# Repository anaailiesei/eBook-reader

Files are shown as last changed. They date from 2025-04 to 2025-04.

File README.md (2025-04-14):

# OpenBook

## 1. Diagrama Bloc
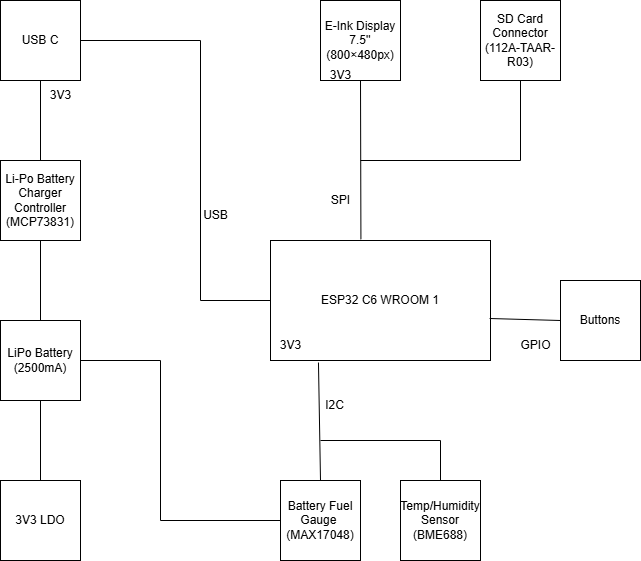
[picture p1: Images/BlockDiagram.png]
diagrama


## 2. BOM
|DEVICE |PARTS |PURCHASE URL |DATASHEET URL |
|---|---|---|---|
|ADAFRUIT_LEDCHIP-LED0603 |CHG_LED |https://www.tme.eu/en/details/kp-1608surck/smd-colour-leds/kingbright-electronic/ |https://www.alldatasheet.com/datasheet-pdf/pdf/1153370/TO-GRACE/KP-1608SURCK.html |
|EAGLE-LTSPICE_C |EPD_C5 |https://www.digikey.com/en/products/detail/samsung-electro-mechanics/CL05B104KB5NNNC/11696318 |https://www.digikey.com/en/products/detail/samsung-electro-mechanics/CL05B104KB5NNNC/11696318 |
|ESP32_WROVER_EAGLE-LTSPICE_R |R3 |https://www.digikey.com/en/products/detail/cts-resistor-products/73L1R47J/1543472 |https://www.digikey.com/en/products/detail/cts-resistor-products/73L1R47J/1543472 |
|ESP32_WROVER_EAGLE-LTSPICE_R |R1_PWRUSB |https://www.digikey.com/en/products/detail/yageo/RC0402JR-07100KL/726416 |https://www.digikey.com/en/products/detail/yageo/RC0402JR-07100KL/726416 |
|EAGLE-LTSPICE_C |C1, C2, C4_USB, C6, C8, C9, C10, C_DELAY |https://www.digikey.com/en/products/detail/samsung-electro-mechanics/CL05B104KP5NNNC/3886660 |https://www.digikey.com/en/products/detail/samsung-electro-mechanics/CL05B104KP5NNNC/3886660 |
|RCL_CPOL-EUCT3528 |C3 |https://ro.mouser.com/ProductDetail/KEMET/T491B107K006AT?qs=0CYHZL%252BGkuR7Fv7IsnkA2g%3D%3D |https://ro.mouser.com/ProductDetail/KEMET/T491B107K006AT?qs=0CYHZL%252BGkuR7Fv7IsnkA2g%3D%3D |
|ESP32_WROVER_EAGLE-LTSPICE_R |R1, R1_PINH, R1_PINH1, R2_PINH, R2_PINH1, R4, R5, R6, R7, R8, R9, R10, R_BOOT, R_CHANGE, R_CL1, R_RESET|https://www.digikey.com/en/products/detail/yageo/RC0402JR-0710KL/726418 |https://www.digikey.com/en/products/detail/yageo/RC0402JR-0710KL/726418 |
|EAGLE-LTSPICE_C |C7 |https://www.digikey.com/en/products/detail/samsung-electro-mechanics/CL05A106MP5NUNC/3887108 |https://www.digikey.com/en/products/detail/samsung-electro-mechanics/CL05A106MP5NUNC/3887108 |
|112A-TAAR-R03_ATTEND |J4 |https://www.digikey.com/en/products/detail/attend-technology/112A-TAAR-R03/17633923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 |https://www.digikey.com/en/products/detail/attend-technology/112A-TAAR-R03/17633923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 |
|ESP32_WROVER_EAGLE-LTSPICE_R |R_CAPACITOR |https://www.digikey.com/en/products/detail/te-connectivity-passive-product/CRGCQ0402F15R/8576207 |https://www.digikey.com/en/products/detail/te-connectivity-passive-product/CRGCQ0402F15R/8576207 |
|EAGLE-LTSPICE_C |C5 |https://www.digikey.com/en/products/detail/taiyo-yuden/JMK105BJ105KV-F/930583 |https://www.digikey.com/en/products/detail/taiyo-yuden/JMK105BJ105KV-F/930583 |
|EAGLE-LTSPICE_C |EPD_C1, EPD_C2, EPD_C3, EPD_C4, EPD_C6, EPD_C7, EPD_C8, EPD_C9, EPD_C10 |https://www.digikey.com/en/products/detail/murata-electronics/GRM155R61H105KE05D/13531808 |https://www.digikey.com/en/products/detail/murata-electronics/GRM155R61H105KE05D/13531808 |
|ESP32_WROVER_EAGLE-LTSPICE_R |R2 |https://www.digikey.com/en/products/detail/stackpole-electronics-inc/RMCF0402FT2R20/4376617 |https://www.digikey.com/en/products/detail/stackpole-electronics-inc/RMCF0402FT2R20/4376617 |
|ESP32_WROVER_EAGLE-LTSPICE_R |R1_BAT |https://www.digikey.com/en/products/detail/panasonic-electronic-components/ERJ-2RKF2000X/192215 |https://www.digikey.com/en/products/detail/panasonic-electronic-components/ERJ-2RKF2000X/192215 |
|ESP32_WROVER_SPARKFUN-DISCRETESEMI_MOSFET_PCH |Q1, Q2 |https://ro.mouser.com/ProductDetail/Diodes-Incorporated/DMG2305UXQ-7?qs=60RJRzIpcl%2FUiAojHt1c9w%3D%3D |https://ro.mouser.com/ProductDetail/Diodes-Incorporated/DMG2305UXQ-7?qs=60RJRzIpcl%2FUiAojHt1c9w%3D%3D |
|ESP32_WROVER_EAGLE-LTSPICE_R |R2_BAT |https://www.digikey.com/en/products/detail/panasonic-electronic-components/ERJ-2RKF2001X/192194 |https://www.digikey.com/en/products/detail/panasonic-electronic-components/ERJ-2RKF2001X/192194 |
|EAGLE-LTSPICE_C |C1_BAT, C1_BAT1, C1_BAT2, C2_BAT, C5_USB |https://www.digikey.com/en/products/detail/samsung-electro-mechanics/CL05A475KQ5NRNC/3887139 |https://www.digikey.com/en/products/detail/samsung-electro-mechanics/CL05A475KQ5NRNC/3887139 |
|EAGLE-LTSPICE_C |C4 |https://www.digikey.com/en/products/detail/murata-electronics/GRM155C61E475ME15D/16821133 |https://www.digikey.com/en/products/detail/murata-electronics/GRM155C61E475ME15D/16821133 |
|ESP32_WROVER_EAGLE-LTSPICE_R |R2-USB, R2-USB1 |https://www.digikey.com/en/products/detail/panasonic-electronic-components/ERA-2AEB512X/1706022 |https://www.digikey.com/en/products/detail/panasonic-electronic-components/ERA-2AEB512X/1706022 |
|744043680IND_4828-WE-TPC_WRE |L1 |https://www.digikey.com/en/products/detail/w%C3%BCrth-elektronik/744043680/1638515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 |https://www.digikey.com/en/products/detail/w%C3%BCrth-elektronik/744043680/1638515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 |
|BD5229G-TR |IC1 |https://www.digikey.com/en/products/detail/rohm-semiconductor/BD5229G-TR/658502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 |https://www.digikey.com/en/products/detail/rohm-semiconductor/BD5229G-TR/658502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 |
|ESP32_WROVER_BME680_BME680 |SENSOR2 |https://www.digikey.com/en/products/detail/bosch-sensortec/BME680/7401317 |https://www.digikey.com/en/products/detail/bosch-sensortec/BME680/7401317 |
|BUTTON_CUSYOMV1. |BOOT_BUTTON, CHANGE_BUTTON, RESET_BUTTON |https://www.digikey.com/en/products/detail/c-k/KMS221G-LFS/2043218?s=N4IgTCBcDaINIFkDKYwEYDiAZAYkkAugL5A |https://www.digikey.com/en/products/detail/c-k/KMS221G-LFS/2043218?s=N4IgTCBcDaINIFkDKYwEYDiAZAYkkAugL5A |
|CPH3225A |C10_SUPERCAP |https://www.snapeda.com/api/url_track_click_mouser/?unipart_id=562593&manufacturer=Seiko Instruments&part_name=CPH3225A&search_term=None |https://www.snapeda.com/api/url_track_click_mouser/?unipart_id=562593&manufacturer=Seiko Instruments&part_name=CPH3225A&search_term=None |
|DS3231SN# |U3 |https://www.snapeda.com/api/url_track_click_mouser/?unipart_id=99048&manufacturer=Analog Devices&part_name=DS3231SN#&search_term=None |https://www.snapeda.com/api/url_track_click_mouser/?unipart_id=99048&manufacturer=Analog Devices&part_name=DS3231SN#&search_term=None |
|ESP32-C6-WROOM-1-N8 |U2 |https://www.digikey.com/en/products/detail/espressif-systems/ESP32-C6-WROOM-1-N8/17728866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|https://www.digikey.com/en/products/detail/espressif-systems/ESP32-C6-WROOM-1-N8/17728866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|
|ESP32C6_VARISTORCN1812 |PFMF.050.1 |https://www.digikey.com/en/products/detail/epcos-tdk-electronics/B72580T0400K062/4945372 |https://www.digikey.com/en/products/detail/epcos-tdk-electronics/B72580T0400K062/4945372 |
|ESP32_WROVER_AVX---SD0805S020S1R0_AVX_SD0805S020S1R0_0_0|D2 |https://www.digikey.com/en/products/detail/kyocera-avx/SD0805S020S1R0/3749517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 |https://www.digikey.com/en/products/detail/kyocera-avx/SD0805S020S1R0/3749517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 |
|ESP32_WROVER_SPARKFUN-IC-POWER_MCP73831 |MCP73831 |https://www.digikey.com/en/products/detail/microchip-technology/MCP73831T-2ACI-OT/964301 |https://www.digikey.com/en/products/detail/microchip-technology/MCP73831T-2ACI-OT/964301 |
|FH34SRJ-24S-0.5SH_99_ |J1 |https://www.digikey.com/en/products/detail/hirose-electric-co-ltd/fh34srj-24s-0-5sh-99/5132529 |https://www.digikey.com/en/products/detail/hirose-electric-co-ltd/fh34srj-24s-0-5sh-99/5132529 |
|MAX17048G+T10 |U4 |https://www.snapeda.com/api/url_track_click_mouser/?unipart_id=329239&manufacturer=Analog Devices&part_name=MAX17048G+T10&search_term=None |https://www.digikey.com/en/products/detail/analog-devices-inc-maxim-integrated/max17048g-t10/3758921 |
|MBR0530. |D3, D4, D5 |https://www.digikey.com/en/products/detail/smc-diode-solutions/MBR0530/16692306 |https://www.digikey.com/en/products/detail/smc-diode-solutions/MBR0530/16692306 |
|PGB1010603MR. |D6, D8, D9, D10, D11, D12 |https://www.digikey.com/en/products/detail/littelfuse-inc/PGB1010603MR/715755 |https://www.digikey.com/en/products/detail/littelfuse-inc/PGB1010603MR/715755 |
|QWIIC_CONNECTORJS-1MM |J3 |https://www.digikey.lt/en/products/detail/jst-sales-america-inc/SM04B-SRSS-TB/926710 |https://www.digikey.lt/en/products/detail/jst-sales-america-inc/SM04B-SRSS-TB/926710 |
|SAMACSYS_PARTS_USB4110-GF-A |J2 |https://www.digikey.lt/en/products/detail/gct/usb4110-gf-a/10384547 |https://www.digikey.lt/en/products/detail/gct/usb4110-gf-a/10384547 |
|ESP32_WROVER_AVX---SD0805S020S1R0_AVX_SD0805S020S1R0_0_0|D7 |https://www.digikey.lt/en/products/detail/kyocera-avx/sd0805s020s1r0/3749517 |https://www.digikey.lt/en/products/detail/kyocera-avx/sd0805s020s1r0/3749517 |
|SI1308EDL-T1-GE3 |Q3 |https://www.digikey.lt/en/products/detail/vishay-siliconix/si1308edl-t1-ge3/4876435 |https://www.digikey.lt/en/products/detail/vishay-siliconix/si1308edl-t1-ge3/4876435 |
|USBLC6-2SC6Y |D1 |https://www.digikey.lt/en/products/detail/stmicroelectronics/usblc6-2sc6y/2819177 |https://www.digikey.lt/en/products/detail/stmicroelectronics/usblc6-2sc6y/2819177 |
|W25Q512JVEIQ |U1 |https://www.digikey.lt/en/products/detail/winbond-electronics/w25q512jveiq/10244706 |https://www.digikey.lt/en/products/detail/winbond-electronics/w25q512jveiq/10244706 |
|XC6220A331MR-G |IC4 |https://www.digikey.lt/en/products/detail/torex-semiconductor-ltd/xc6220a331mr-g/10165775 |https://www.digikey.lt/en/products/detail/torex-semiconductor-ltd/xc6220a331mr-g/10165775 |
|TP |TP1, TP2, TP3, TP4, TP5, TP6, TP7, TP8, TP9, TP10, TP11, TP12, TP13, TP14, TP15, TP16, TP17 | | |
|SJ |SJ1 | | |

## 3. Descrierea în detaliu a funcționalității hardware
| Nume | Descriere | Pini comunicare ESP32-C6 | Comunicare |
|---|---|---|---|
| ESP32-C6-WROOM-1 | MCU RISC-V pe 32 de biți la 160MHz, cu memorie SRAM de 512KB + 16KB și flash extern de 8MB | USB 2.0, SPI, I2C, UART, GPIO | - |
| 7.5" e-Paper Display | E-Paper de 7.5 inch, 800x480 pixeli, alb-negru, cu contrast 8:1, refresh rapid (sub 1s) | SPI + CS, DC, RST, BUSY | SPI |
| BME688 Sensor | Senzor  pentru temperatură, umiditate, presiune și calitatea aerului | SDA, SCL | I2C |
| MAX17048 Fuel Gauge | Gestionare baterie | I2C | I2C |
| MCP73831 Charger | Gestionare baterie | GPIO for control | GPIO |
| Buttons | Butoane fizice tactile cu debouncing hardware prin filtre RC | 3x GPIOs | GPIO |
| USB-C Connector | Pentru încărcare și transfer de date USB 2.0, cu protecție ESD și posibil suport pentru Power Delivery | USB-D+/D- (native USB) | USB |
| SD Card Connector | Pentru memorie | - | SPI |
| DS3231 RTC | Ceas Real Time | I2C | I2C |
| Qwiic/Stemma Connector | Expansiune conector senzori | I2C | I2C |
| LDO Voltage Regulator  | Genereaza o singură șină de alimentare de 3.3V | - | - |
| Baterie (2500mAh) | Baterie Li-Polimer de 2500mAh, 3.7V. Consum redus în deep sleep (sub 50µA) și alimentare de 3.3V pentru sistem | - | - |

## 4. Asezarea componentelor in carcasa

* PCB-ul are o grosime de 1mm si este sprijinit de capacul carcasei
* Bateria este sprijinita de capacul carcasei
* Ecranul este sprijinit de spatele PCB-ului

## 5. Pasi de implementare
1. Am realizat schematicul cu ajutor componentelor din libraria data si schematicul model.
2. De la schematic am generat PCB-ul 2D. Am adaugat componentele pe PCB conform schemei date.
3. Am facut un nou net class pentru liniile de putere (SupplyNets) si am adaugat liniile corespunzatoare. Am facut o regula speciala pentru grosimea acestor linii (0.3mm).
4. Am rutat manual liniile de putere pentru a ma asigura ca nu folosesc vias-uri prea multe (a fost necesar sa folosesc vias-uri o singura data). Am facut apoi autorutarea.
5. Am adaugat planurile de masa si via stiches.
6. Am adaugat pentru fiecare componenta un model 3D. Am tinut cont la elementele polarizate sau marcate de orientarea componentei pentru o reprezentare cat mai realista.
7. Am modelat bateria si ecranul conform datasheetului si le-am asamblat in carcasa.

## 6. Decizii

* Eroare SMD-Hole (Samacsys-Parts): Am rezolvat mutand gaurile cu 0.1 mm.

* Eroare Copper width SMD (Net Class: SupplyLines): Am modificat pad-urile de la bobina (Ind_4828) sa fie mai mari (0.5 x 0.5 mm) ca sa permita conectarea cu liniile de putere.

* Eroare Copper width SMD (Net Class: SupplyLines): Am modificat pad-urile de la SON50P200X sa fie mai mari (de la 0.27 mm la 0.3 mm) ca sa permita conectarea cu liniile de putere (VBAT).

* Am aprobat erorile de Power Pin ... connected to ... din Schematic.

## 7. Dificultati
* Gasirea modelelor 3D pentru fiecare componenta, actualizarea bibliotecii, aranjarea lor sa se potriveasca cu footprint-ul.
* M-am asigurat ca nu am froarte multe vias-uri la traseele de putere si a trebuit sa fac o parte din rutare manual. Nu am putut evita o situatie (traseele ar fi ajuns sa fie exagerat de lungi din cauza ocolirilor daca nu foloseam) si a fost nevoie sa folosesc vias-uri pe un traseu de putere.
* Desi nu am avut de facut modele 3D complexe, aceasta a fost o provocare deoarece a fost prima data cand am facut asa ceva.
* Verificarea ca traseele sa nu contina unghiuri drepte si corectarea lor.

## 8. Imagini PCB
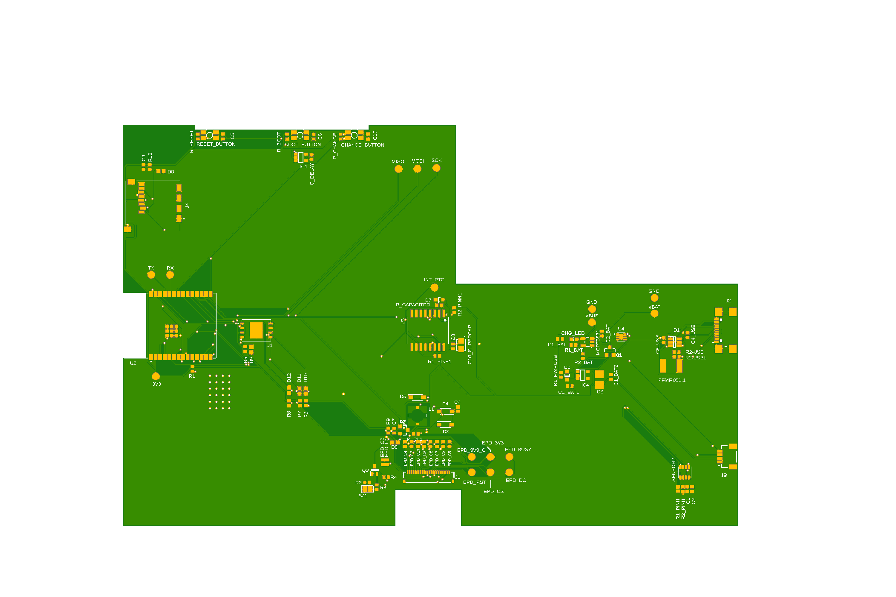
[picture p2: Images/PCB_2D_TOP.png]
imagine1

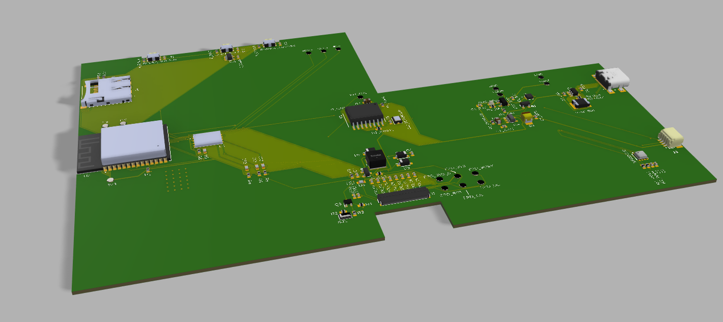
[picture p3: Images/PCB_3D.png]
imagine2


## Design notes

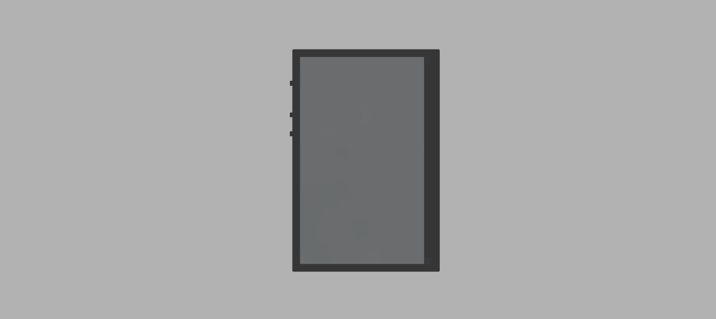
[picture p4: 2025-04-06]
Images/OpenEbook2.png

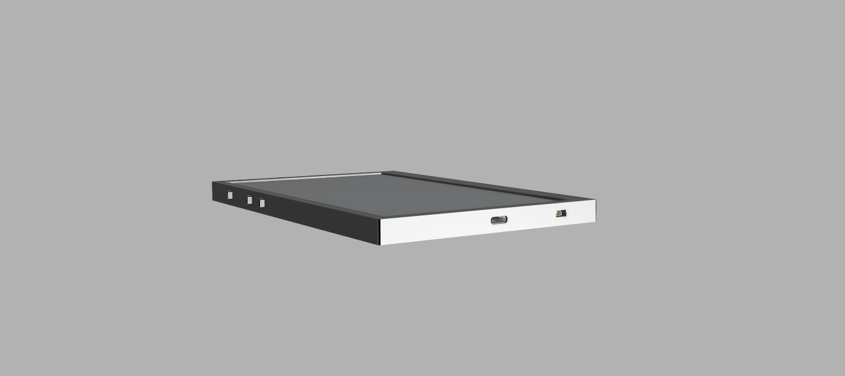
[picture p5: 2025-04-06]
Images/OpenEBook1.png

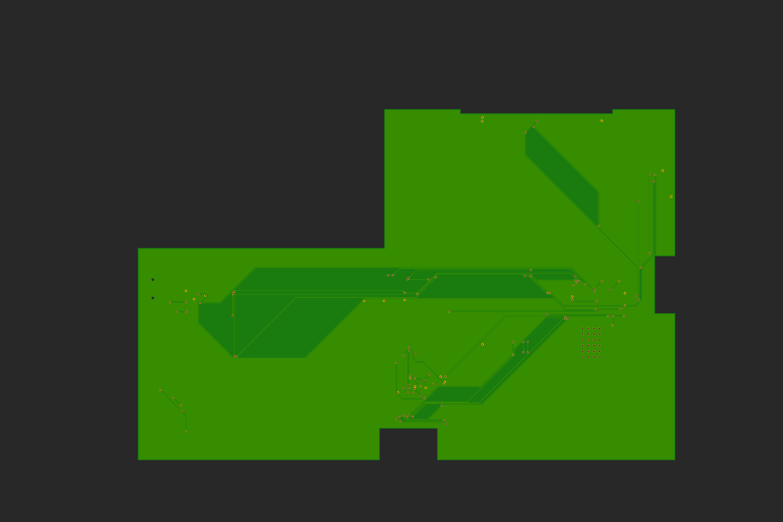
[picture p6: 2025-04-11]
Images/PCB_2D_BOTTOM.png

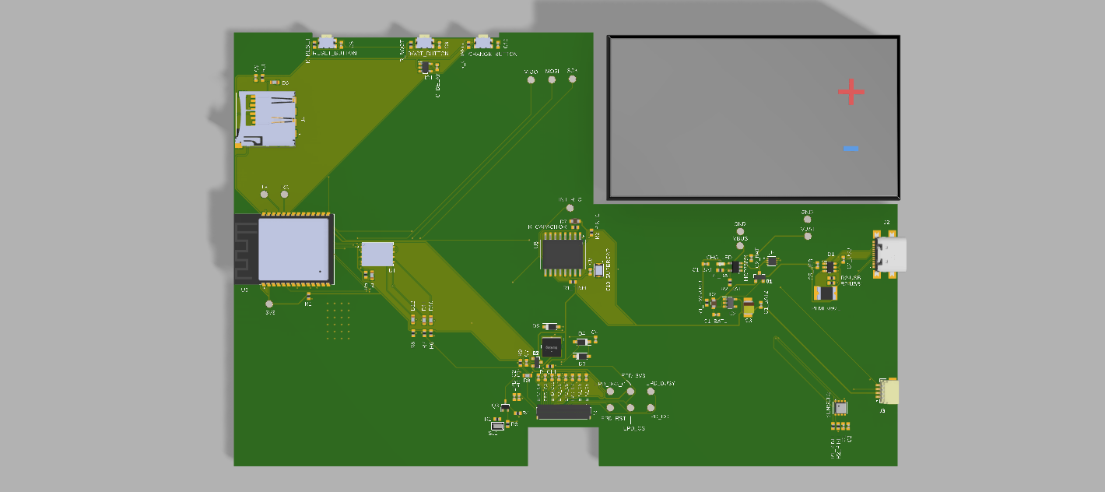
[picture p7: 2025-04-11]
Images/PCB_3D+Battery.png

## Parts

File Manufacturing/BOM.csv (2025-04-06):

Qty | Value | Device | Package | Parts | PURCHASE-URL | DATASHEET-URL | Description | ARROW_PART_NUMBER | ARROW_PRICE-STOCK | AVAILABILITY | CHECK_PRICES | COPYRIGHT | DESCRIPTION | HEIGHT | MANUFACTURER_NAME | MANUFACTURER_PART_NUMBER | MF | MFR_NAME | MOUSER_PART_NUMBER | MOUSER_PRICE-STOCK | MOUSER_TESTING_PART_NUMBER | MOUSER_TESTING_PRICE-STOCK | MP | PACKAGE | POPULARITY | PRICE | PROD_ID | SNAPEDA_LINK | SPICEPREFIX | VALUE
1 |  | ADAFRUIT_LEDCHIP-LED0603 | ADAFRUIT_CHIP-LED0603 | CHG_LED | https://www.tme.eu/en/details/kp-1608surck/smd-colour-leds/kingbright-electronic/ | https://www.alldatasheet.com/datasheet-pdf/pdf/1153370/TO-GRACE/KP-1608SURCK.html | LED
1 |  | SJ | SJ | SJ1 |  |  | SMD solder JUMPER |  |  |  |  |  |  |  |  |  |  |  |  |  |  |  |  |  | 3
1 | 0.1uF/50V | EAGLE-LTSPICE_C | EAGLE-LTSPICE_C0402 | EPD_C5 | https://www.digikey.com/en/products/detail/samsung-electro-mechanics/CL05B104KB5NNNC/11696318 | https://www.digikey.com/en/products/detail/samsung-electro-mechanics/CL05B104KB5NNNC/11696318 | CAPACITOR, European symbol
1 | 0.47 | ESP32_WROVER_EAGLE-LTSPICE_R | ESP32_WROVER_EAGLE-LTSPICE_R0402 | R3 | https://www.digikey.com/en/products/detail/cts-resistor-products/73L1R47J/1543472 | https://www.digikey.com/en/products/detail/cts-resistor-products/73L1R47J/1543472 | RESISTOR, European symbol
1 | 100K | ESP32_WROVER_EAGLE-LTSPICE_R | ESP32_WROVER_EAGLE-LTSPICE_R0402 | R1_PWRUSB | https://www.digikey.com/en/products/detail/yageo/RC0402JR-07100KL/726416 | https://www.digikey.com/en/products/detail/yageo/RC0402JR-07100KL/726416 | RESISTOR, European symbol
8 | 100nF | EAGLE-LTSPICE_C | EAGLE-LTSPICE_C0402 | C1, C2, C4_USB, C6, C8, C9, C10, C_DELAY | https://www.digikey.com/en/products/detail/samsung-electro-mechanics/CL05B104KP5NNNC/3886660 | https://www.digikey.com/en/products/detail/samsung-electro-mechanics/CL05B104KP5NNNC/3886660 | CAPACITOR, European symbol
1 | 100uF TANT | RCL_CPOL-EUCT3528 | RCL_CT3528 | C3 | https://ro.mouser.com/ProductDetail/KEMET/T491B107K006AT?qs=0CYHZL%252BGkuR7Fv7IsnkA2g%3D%3D | https://ro.mouser.com/ProductDetail/KEMET/T491B107K006AT?qs=0CYHZL%252BGkuR7Fv7IsnkA2g%3D%3D | POLARIZED CAPACITOR, European symbol |  |  |  |  |  |  |  |  |  |  |  |  |  |  |  |  |  | 0 |  |  |  | C
16 | 10K | ESP32_WROVER_EAGLE-LTSPICE_R | ESP32_WROVER_EAGLE-LTSPICE_R0402 | R1, R1_PINH, R1_PINH1, R2_PINH, R2_PINH1, R4, R5, R6, R7, R8, R9, R10, R_BOOT, R_CHANGE, R_CL1, R_RESET | https://www.digikey.com/en/products/detail/yageo/RC0402JR-0710KL/726418 | https://www.digikey.com/en/products/detail/yageo/RC0402JR-0710KL/726418 | RESISTOR, European symbol
1 | 10uF | EAGLE-LTSPICE_C | EAGLE-LTSPICE_C0402 | C7 | https://www.digikey.com/en/products/detail/samsung-electro-mechanics/CL05A106MP5NUNC/3887108 | https://www.digikey.com/en/products/detail/samsung-electro-mechanics/CL05A106MP5NUNC/3887108 | CAPACITOR, European symbol
1 | 112A-TAAR-R03_ATTEND | 112A-TAAR-R03_ATTEND | 112ATAARR03ATTEND | J4 | https://www.digikey.com/en/products/detail/attend-technology/112A-TAAR-R03/17633923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 | https://www.digikey.com/en/products/detail/attend-technology/112A-TAAR-R03/17633923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 | Micro SD Card Socket, Push-Push Type, Top Mount, SMT, H=1.83mm, 10u |  |  |  |  |  | Micro SD Card Socket | Push-Push Type | Top Mount | SMT | H=1.83mm | 10u | 1.9mm | ATTEND | 112A-TAAR-R03 ATTEND
1 | 15 | ESP32_WROVER_EAGLE-LTSPICE_R | ESP32_WROVER_EAGLE-LTSPICE_R0402 | R_CAPACITOR | https://www.digikey.com/en/products/detail/te-connectivity-passive-product/CRGCQ0402F15R/8576207 | https://www.digikey.com/en/products/detail/te-connectivity-passive-product/CRGCQ0402F15R/8576207 | RESISTOR, European symbol
1 | 1uF | EAGLE-LTSPICE_C | EAGLE-LTSPICE_C0402 | C5 | https://www.digikey.com/en/products/detail/taiyo-yuden/JMK105BJ105KV-F/930583 | https://www.digikey.com/en/products/detail/taiyo-yuden/JMK105BJ105KV-F/930583 | CAPACITOR, European symbol
9 | 1uF/50V | EAGLE-LTSPICE_C | EAGLE-LTSPICE_C0402 | EPD_C1, EPD_C2, EPD_C3, EPD_C4, EPD_C6, EPD_C7, EPD_C8, EPD_C9, EPD_C10 | https://www.digikey.com/en/products/detail/murata-electronics/GRM155R61H105KE05D/13531808 | https://www.digikey.com/en/products/detail/murata-electronics/GRM155R61H105KE05D/13531808 | CAPACITOR, European symbol
1 | 2.2 | ESP32_WROVER_EAGLE-LTSPICE_R | ESP32_WROVER_EAGLE-LTSPICE_R0402 | R2 | https://www.digikey.com/en/products/detail/stackpole-electronics-inc/RMCF0402FT2R20/4376617 | https://www.digikey.com/en/products/detail/stackpole-electronics-inc/RMCF0402FT2R20/4376617 | RESISTOR, European symbol
1 | 200 | ESP32_WROVER_EAGLE-LTSPICE_R | ESP32_WROVER_EAGLE-LTSPICE_R0402 | R1_BAT | https://www.digikey.com/en/products/detail/panasonic-electronic-components/ERJ-2RKF2000X/192215 | https://www.digikey.com/en/products/detail/panasonic-electronic-components/ERJ-2RKF2000X/192215 | RESISTOR, European symbol
2 | 20V/4.2A/52mO/1.4W | ESP32_WROVER_SPARKFUN-DISCRETESEMI_MOSFET_PCH | ESP32_WROVER_SPARKFUN-DISCRETESEMI_SOT23-3 | Q1, Q2 | https://ro.mouser.com/ProductDetail/Diodes-Incorporated/DMG2305UXQ-7?qs=60RJRzIpcl%2FUiAojHt1c9w%3D%3D | https://ro.mouser.com/ProductDetail/Diodes-Incorporated/DMG2305UXQ-7?qs=60RJRzIpcl%2FUiAojHt1c9w%3D%3D | P-channel MOSFETs
1 | 2K | ESP32_WROVER_EAGLE-LTSPICE_R | ESP32_WROVER_EAGLE-LTSPICE_R0402 | R2_BAT | https://www.digikey.com/en/products/detail/panasonic-electronic-components/ERJ-2RKF2001X/192194 | https://www.digikey.com/en/products/detail/panasonic-electronic-components/ERJ-2RKF2001X/192194 | RESISTOR, European symbol
1 | 3V3 | TP | TP20R | TP16 |  |  | Test pad
5 | 4.7uF | EAGLE-LTSPICE_C | EAGLE-LTSPICE_C0402 | C1_BAT, C1_BAT1, C1_BAT2, C2_BAT, C5_USB | https://www.digikey.com/en/products/detail/samsung-electro-mechanics/CL05A475KQ5NRNC/3887139 | https://www.digikey.com/en/products/detail/samsung-electro-mechanics/CL05A475KQ5NRNC/3887139 | CAPACITOR, European symbol
1 | 4.7uF/25V | EAGLE-LTSPICE_C | EAGLE-LTSPICE_C0402 | C4 | https://www.digikey.com/en/products/detail/murata-electronics/GRM155C61E475ME15D/16821133 | https://www.digikey.com/en/products/detail/murata-electronics/GRM155C61E475ME15D/16821133 | CAPACITOR, European symbol
2 | 5k1 | ESP32_WROVER_EAGLE-LTSPICE_R | ESP32_WROVER_EAGLE-LTSPICE_R0402 | R2-USB, R2-USB1 | https://www.digikey.com/en/products/detail/panasonic-electronic-components/ERA-2AEB512X/1706022 | https://www.digikey.com/en/products/detail/panasonic-electronic-components/ERA-2AEB512X/1706022 | RESISTOR, European symbol
1 | 68uH | 744043680IND_4828-WE-TPC_WRE | IND_4828-WE-TPC_WRE | L1 | https://www.digikey.com/en/products/detail/w%C3%BCrth-elektronik/744043680/1638515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 | https://www.digikey.com/en/products/detail/w%C3%BCrth-elektronik/744043680/1638515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 |  |  |  |  |  | Copyright (C) 2024 Ultra Librarian. All rights reserved. |  |  |  | 744043680 |  | Wurth Electronics
1 | BD5229G-TR | BD5229G-TR | SOT95P280X125-5N | IC1 | https://www.digikey.com/en/products/detail/rohm-semiconductor/BD5229G-TR/658502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 | https://www.digikey.com/en/products/detail/rohm-semiconductor/BD5229G-TR/658502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 | Voltage Detector with Adjustable Delay Time: CMOS processes are utilized to develop high precision, low current consumption CMOS reset ICs that allow arbitrary setting of the delay time. The extensive lineup includes both Nch Open Drain and CMOS output types in a wide range of detection voltages (from 2.3V to 6.0V, in 0.1V steps), enabling selection of the ideal solution based on customer requirements. In addition, the entire series is of course both lead-free and RoHS-compliant. |  |  |  |  |  | Voltage Detector with Adjustable Delay Time: CMOS processes are utilized to develop high precision | low current consumption CMOS reset ICs that allow arbitrary setting of the delay time. The extensive lineup includes both Nch Open Drain and CMOS output types in a wide range of detection voltages (from 2.3V to 6.0V | in 0.1V steps) | enabling selection of the ideal solution based on customer requirements. In addition | the entire series is of course both lead-free and RoHS-compliant. | 1.25mm | ROHM Semiconductor | BD5229G-TR |  |  | 755-BD5229G-TR | https://www.mouser.co.uk/ProductDetail/ROHM-Semiconductor/BD5229G-TR?qs=4kLU8WoGk0vvnhrrYwdszw%3D%3D
1 | BME680 | ESP32_WROVER_BME680_BME680 | ESP32_WROVER_BME680_PSON80P300X300X100-8N | SENSOR2 | https://www.digikey.com/en/products/detail/bosch-sensortec/BME680/7401317 | https://www.digikey.com/en/products/detail/bosch-sensortec/BME680/7401317 | Integrated Environmental Unit |  |  | Unavailable |  |  | Integrated Environmental Unit |  |  |  | Bosch Sensortec |  |  |  |  |  | BME680 | LGA-8 Bosch Tools |  | None
3 | BUTTON_CUSYOMV1. | BUTTON_CUSYOMV1. | MYBUTTON | BOOT_BUTTON, CHANGE_BUTTON, RESET_BUTTON | https://www.digikey.com/en/products/detail/c-k/KMS221G-LFS/2043218?s=N4IgTCBcDaINIFkDKYwEYDiAZAYkkAugL5A | https://www.digikey.com/en/products/detail/c-k/KMS221G-LFS/2043218?s=N4IgTCBcDaINIFkDKYwEYDiAZAYkkAugL5A
1 | CPH3225A | CPH3225A | CAPCP3225X100N | C10_SUPERCAP | https://www.snapeda.com/api/url_track_click_mouser/?unipart_id=562593&manufacturer=Seiko Instruments&part_name=CPH3225A&search_term=None | https://www.snapeda.com/api/url_track_click_mouser/?unipart_id=562593&manufacturer=Seiko Instruments&part_name=CPH3225A&search_term=None | Cap 0.011F 3.3V 1210 Flat Check availability |  |  | Not in stock | https://www.snapeda.com/parts/CPH3225A/Seiko+Instruments/view-part/?ref=eda |  | 11 mF (EDLC) Supercapacitor 3.3 V 1210 (3225 Metric) - - |  |  |  | Seiko Instruments |  |  |  |  |  | CPH3225A | 1210 Seiko |  | None |  | https://www.snapeda.com/parts/CPH3225A/Seiko+Instruments/view-part/?ref=snap
1 | DS3231SN# | DS3231SN# | SOIC127P1032X265-16N | U3 | https://www.snapeda.com/api/url_track_click_mouser/?unipart_id=99048&manufacturer=Analog Devices&part_name=DS3231SN#&search_term=None | https://www.snapeda.com/api/url_track_click_mouser/?unipart_id=99048&manufacturer=Analog Devices&part_name=DS3231SN#&search_term=None | Real Time Clock Serial 16-Pin SOIC W T/R Check availability |  |  | In Stock | https://www.snapeda.com/parts/DS3231SN%23/Analog+Devices/view-part/?ref=eda |  | Extremely Accurate I²C-Integrated RTC/TCXO/Crystal |  |  |  | Analog Devices |  |  |  |  |  | DS3231SN# | SOIC-16 Maxim |  | None |  | https://www.snapeda.com/parts/DS3231SN%23/Analog+Devices/view-part/?ref=snap
1 | EPD_3V3 | TP | TP20R | TP17 |  |  | Test pad
1 | EPD_3V3_C | TP | TP20R | TP13 |  |  | Test pad
1 | EPD_BUSY | TP | TP20R | TP9 |  |  | Test pad
1 | EPD_CS | TP | TP20R | TP10 |  |  | Test pad
1 | EPD_DC | TP | TP20R | TP11 |  |  | Test pad
1 | EPD_RST | TP | TP20R | TP12 |  |  | Test pad
1 | ESP32-C6-WROOM-1-N8 | ESP32-C6-WROOM-1-N8 | XCVR_ESP32-C6-WROOM-1-N8 | U2 | https://www.digikey.com/en/products/detail/espressif-systems/ESP32-C6-WROOM-1-N8/17728866 | https://www.digikey.com/en/products/detail/espressif-systems/ESP32-C6-WROOM-1-N8/17728866 | Check availability |  |  | In Stock | https://www.snapeda.com/parts/ESP32-C6-WROOM-1-N8/Espressif+Systems/view-part/?ref=eda |  | Multiprotocol Modules ESP32-C6 module | Wi-Fi 6 in 2.4 GHz band | Bluetooth 5 | Zigbee 3.0 and Thread. ESP34-WROOM Compatible - ENGINEERING SAMPLE |  |  |  | Espressif Systems |  |  |  |  |  | ESP32-C6-WROOM-1-N8 | None | None
1 | ESP32C6_VARISTORCN1812 | ESP32C6_VARISTORCN1812 | ESP32C6_VARISTOR_CT/CN1812 | PFMF.050.1 | https://www.digikey.com/en/products/detail/epcos-tdk-electronics/B72580T0400K062/4945372 | https://www.digikey.com/en/products/detail/epcos-tdk-electronics/B72580T0400K062/4945372 | VARISTOR |  |  |  |  |  |  |  |  |  |  |  |  |  |  |  |  |  | 0
1 | ESP32_WROVER_AVX---SD0805S020S1R0_AVX_SD0805S020S1R0_0_0 | ESP32_WROVER_AVX---SD0805S020S1R0_AVX_SD0805S020S1R0_0_0 | ESP32_WROVER_AVX---SD0805S020S1R0_AVX_SD0805S020S1R0_0 | D2 | https://www.digikey.com/en/products/detail/kyocera-avx/SD0805S020S1R0/3749517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 | https://www.digikey.com/en/products/detail/kyocera-avx/SD0805S020S1R0/3749517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 | Schottky Barrier Rectifier Diode
1 | ESP32_WROVER_SPARKFUN-IC-POWER_MCP73831 | ESP32_WROVER_SPARKFUN-IC-POWER_MCP73831 | ESP32_WROVER_SPARKFUN-IC-POWER_SOT23-5 | MCP73831 | https://www.digikey.com/en/products/detail/microchip-technology/MCP73831T-2ACI-OT/964301 | https://www.digikey.com/en/products/detail/microchip-technology/MCP73831T-2ACI-OT/964301 | MCP73831T Li-Ion, Li-Pol Controller |  |  |  |  |  |  |  |  |  |  |  |  |  |  |  |  |  |  |  | IC-09995
1 | FH34SRJ-24S-0.5SH_99_ | FH34SRJ-24S-0.5SH_99_ | FH34SRJ24S05SH99 | J1 | https://www.digikey.com/en/products/detail/hirose-electric-co-ltd/fh34srj-24s-0-5sh-99/5132529 | https://www.digikey.com/en/products/detail/hirose-electric-co-ltd/fh34srj-24s-0-5sh-99/5132529 | (0.50mm) Surface Mount, Right Angle |  |  |  |  |  | 24 Position FFC | FPC Connector Contacts | (0.50mm) Surface Mount | Right Angle | 1.1mm | Hirose | FH34SRJ-24S-0.5SH(99) |  |  | 798-FH34SRJ24S05SH99 | https://www.mouser.co.uk/ProductDetail/Hirose-Connector/FH34SRJ-24S-0.5SH99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
2 | GND | TP | TP20R | TP4, TP5 |  |  | Test pad
1 | INT_RTC | TP | TP20R | TP15 |  |  | Test pad
1 | MAX17048G+T10 | MAX17048G+T10 | SON50P200X200X80-9N | U4 | https://www.snapeda.com/api/url_track_click_mouser/?unipart_id=329239&manufacturer=Analog Devices&part_name=MAX17048G+T10&search_term=None | https://www.digikey.com/en/products/detail/analog-devices-inc-maxim-integrated/max17048g-t10/3758921 | Check availability |  |  | In Stock | https://www.snapeda.com/parts/MAX17048G+T10/Analog+Devices/view-part/?ref=eda |  | 3µA 1-Cell/2-Cell Fuel Gauge with ModelGauge |  |  |  | Analog Devices |  |  |  |  |  | MAX17048G+T10 | TDFN-8 Maxim |  | None |  | https://www.snapeda.com/parts/MAX17048G+T10/Analog+Devices/view-part/?ref=snap
3 | MBR0530. | MBR0530. | SOD3716X135N | D3, D4, D5 | https://www.digikey.com/en/products/detail/smc-diode-solutions/MBR0530/16692306 | https://www.digikey.com/en/products/detail/smc-diode-solutions/MBR0530/16692306 | ON SEMICONDUCTOR - MBR0530 - DIODE, SCHOTTKY, 0.5A, 30V, SOD-123
1 | MISO | TP | TP20R | TP6 |  |  | Test pad
1 | MOSI | TP | TP20R | TP7 |  |  | Test pad
6 | PGB1010603MR. | PGB1010603MR. | DIOC1608X36N | D6, D8, D9, D10, D11, D12 | https://www.digikey.com/en/products/detail/littelfuse-inc/PGB1010603MR/715755 | https://www.digikey.com/en/products/detail/littelfuse-inc/PGB1010603MR/715755 | Check availability
1 | QWIIC_RIGHT_ANGLE | QWIIC_CONNECTORJS-1MM | JST04_1MM_RA | J3 | https://www.digikey.lt/en/products/detail/jst-sales-america-inc/SM04B-SRSS-TB/926710 | https://www.digikey.lt/en/products/detail/jst-sales-america-inc/SM04B-SRSS-TB/926710 | SparkFun I2C Standard Qwiic Connector |  |  |  |  |  |  |  |  |  |  |  |  |  |  |  |  |  |  |  | CONN-13694 |  |  | QWIIC_RIGHT_ANGLE
1 | RX | TP | TP20R | TP2 |  |  | Test pad
1 | SAMACSYS_PARTS_USB4110-GF-A | SAMACSYS_PARTS_USB4110-GF-A | SAMACSYS_PARTS_USB4110GFA | J2 | https://www.digikey.lt/en/products/detail/gct/usb4110-gf-a/10384547 | https://www.digikey.lt/en/products/detail/gct/usb4110-gf-a/10384547 | CONN USB 2.0 TYPE-C R/A SMT |  |  |  |  |  | CONN USB 2.0 TYPE-C R/A SMT | 3.26mm | GCT (GLOBAL CONNECTOR TECHNOLOGY) | USB4110-GF-A |  |  | 640-USB4110-GF-A | https://www.mouser.co.uk/ProductDetail/GCT/USB4110-GF-A?qs=KUoIvG%2F9IlYiZvIXQjyJeA%3D%3D
1 | SCK | TP | TP20R | TP8 |  |  | Test pad
1 | SD0805S020S1R0 | ESP32_WROVER_AVX---SD0805S020S1R0_AVX_SD0805S020S1R0_0_0 | ESP32_WROVER_AVX---SD0805S020S1R0_AVX_SD0805S020S1R0_0 | D7 | https://www.digikey.lt/en/products/detail/kyocera-avx/sd0805s020s1r0/3749517 | https://www.digikey.lt/en/products/detail/kyocera-avx/sd0805s020s1r0/3749517 | Schottky Barrier Rectifier Diode
1 | SI1308EDL-T1-GE3 | SI1308EDL-T1-GE3 | SOT65P210X110-3N | Q3 | https://www.digikey.lt/en/products/detail/vishay-siliconix/si1308edl-t1-ge3/4876435 | https://www.digikey.lt/en/products/detail/vishay-siliconix/si1308edl-t1-ge3/4876435 | MOSFET N-Ch 30V 1.5A TrenchFET SC70 Vishay Si1308EDL-T1-GE3 N-channel MOSFET Transistor, 1.5 A, 30 V, 3-Pin SC-70 |  |  | In Stock | https://www.snapeda.com/parts/SI1308EDL-T1-GE3/Vishay+Siliconix/view-part/?ref=eda |  | Si1308EDL-T1-GE3 N-channel MOSFET Transistor | 1.5 A | 30 V | 3-Pin SC-70 | Siliconix / Vishay SI1308EDL-T1-GE3 |  |  |  | Vishay Siliconix |  |  |  |  |  | SI1308EDL-T1-GE3 | SOT-323 Vishay Semiconductor | None |  | https://www.snapeda.com/api/url_track_click_mouser/?unipart_id=274603&manufacturer=Vishay Siliconix&part_name=SI1308EDL-T1-GE3&search_term=None
1 | TX | TP | TP20R | TP1 |  |  | Test pad
1 | USBLC6-2SC6Y | USBLC6-2SC6Y | SOT95P280X145-6N | D1 | https://www.digikey.lt/en/products/detail/stmicroelectronics/usblc6-2sc6y/2819177 | https://www.digikey.lt/en/products/detail/stmicroelectronics/usblc6-2sc6y/2819177 | Low Cap. ESD Protection Auto SOT-23-6 STMicroelectronics USBLC6-2SC6Y, Dual Uni-Directional TVS Diode Array, 6-Pin SOT-23 |  |  | In Stock | https://www.snapeda.com/parts/USBLC6-2SC6Y/STMicroelectronics/view-part/?ref=eda |  | 17V Clamp 5A (8/20µs) Ipp Tvs Diode Surface Mount SOT-23-6 |  |  |  | STMicroelectronics |  |  |  |  |  | USBLC6-2SC6Y | SOT-23-6 STMicroelectronics |  | None |  | https://www.snapeda.com/parts/USBLC6-2SC6Y/STMicroelectronics/view-part/?ref=snap
1 | VBAT | TP | TP20R | TP3 |  |  | Test pad
1 | VBUS | TP | TP20R | TP14 |  |  | Test pad
1 | W25Q512JVEIQ | W25Q512JVEIQ | SON127P600X800X80-9N | U1 | https://www.digikey.lt/en/products/detail/winbond-electronics/w25q512jveiq/10244706 | https://www.digikey.lt/en/products/detail/winbond-electronics/w25q512jveiq/10244706 | Check availability |  |  | In Stock | https://www.snapeda.com/parts/W25Q512JVEIQ/Winbond+Electronics/view-part/?ref=eda |  | FLASH - NOR Memory IC 512Mb (64M x 8) SPI - Quad I/O 133 MHz 8-WSON (8x6) |  |  |  | Winbond Electronics |  |  |  |  |  | W25Q512JVEIQ | Package |  | None |  | https://www.snapeda.com/parts/W25Q512JVEIQ/Winbond+Electronics/view-part/?ref=snap
1 | XC6220A331MR-G | XC6220A331MR-G | SOT95P280X120-5N | IC4 | https://www.digikey.lt/en/products/detail/torex-semiconductor-ltd/xc6220a331mr-g/10165775 | https://www.digikey.lt/en/products/detail/torex-semiconductor-ltd/xc6220a331mr-g/10165775 | LDO Voltage Regulators |  |  |  |  |  | LDO Voltage Regulators | 1.2mm | Torex | XC6220A331MR-G |  |  | 865-XC6220A331MR-G | https://www.mouser.co.uk/ProductDetail/Torex-Semiconductor/XC6220A331MR-G?qs=AsjdqWjXhJ8ZSWznL1J0gg%3D%3D

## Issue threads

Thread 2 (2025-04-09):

PCB unghiuri drepte (2D)

mariamihalcea, 2025-04-09:
# Unghiuri drepte

Cateva trasee trb corectate in 2D, deoarece au unghiuri drepte

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

anaailiesei, 2025-04-11:
Am modificat cu totul rutarea pentru a elimina si vias-urile la liniile de putere si m-am asigurat ca nu mai exista unghiuri drepte.

Closed 2025-04-11.

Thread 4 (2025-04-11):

Readme

mariamihalcea, 2025-04-11:
Readme ul contine deja majoritatea pasilor specificati, insa ar mai putea fi eventual completat cu sectiunea "pasi de implementare"

anaailiesei, 2025-04-11:
Am adaugat si pasii de implementare.

Closed 2025-04-11.

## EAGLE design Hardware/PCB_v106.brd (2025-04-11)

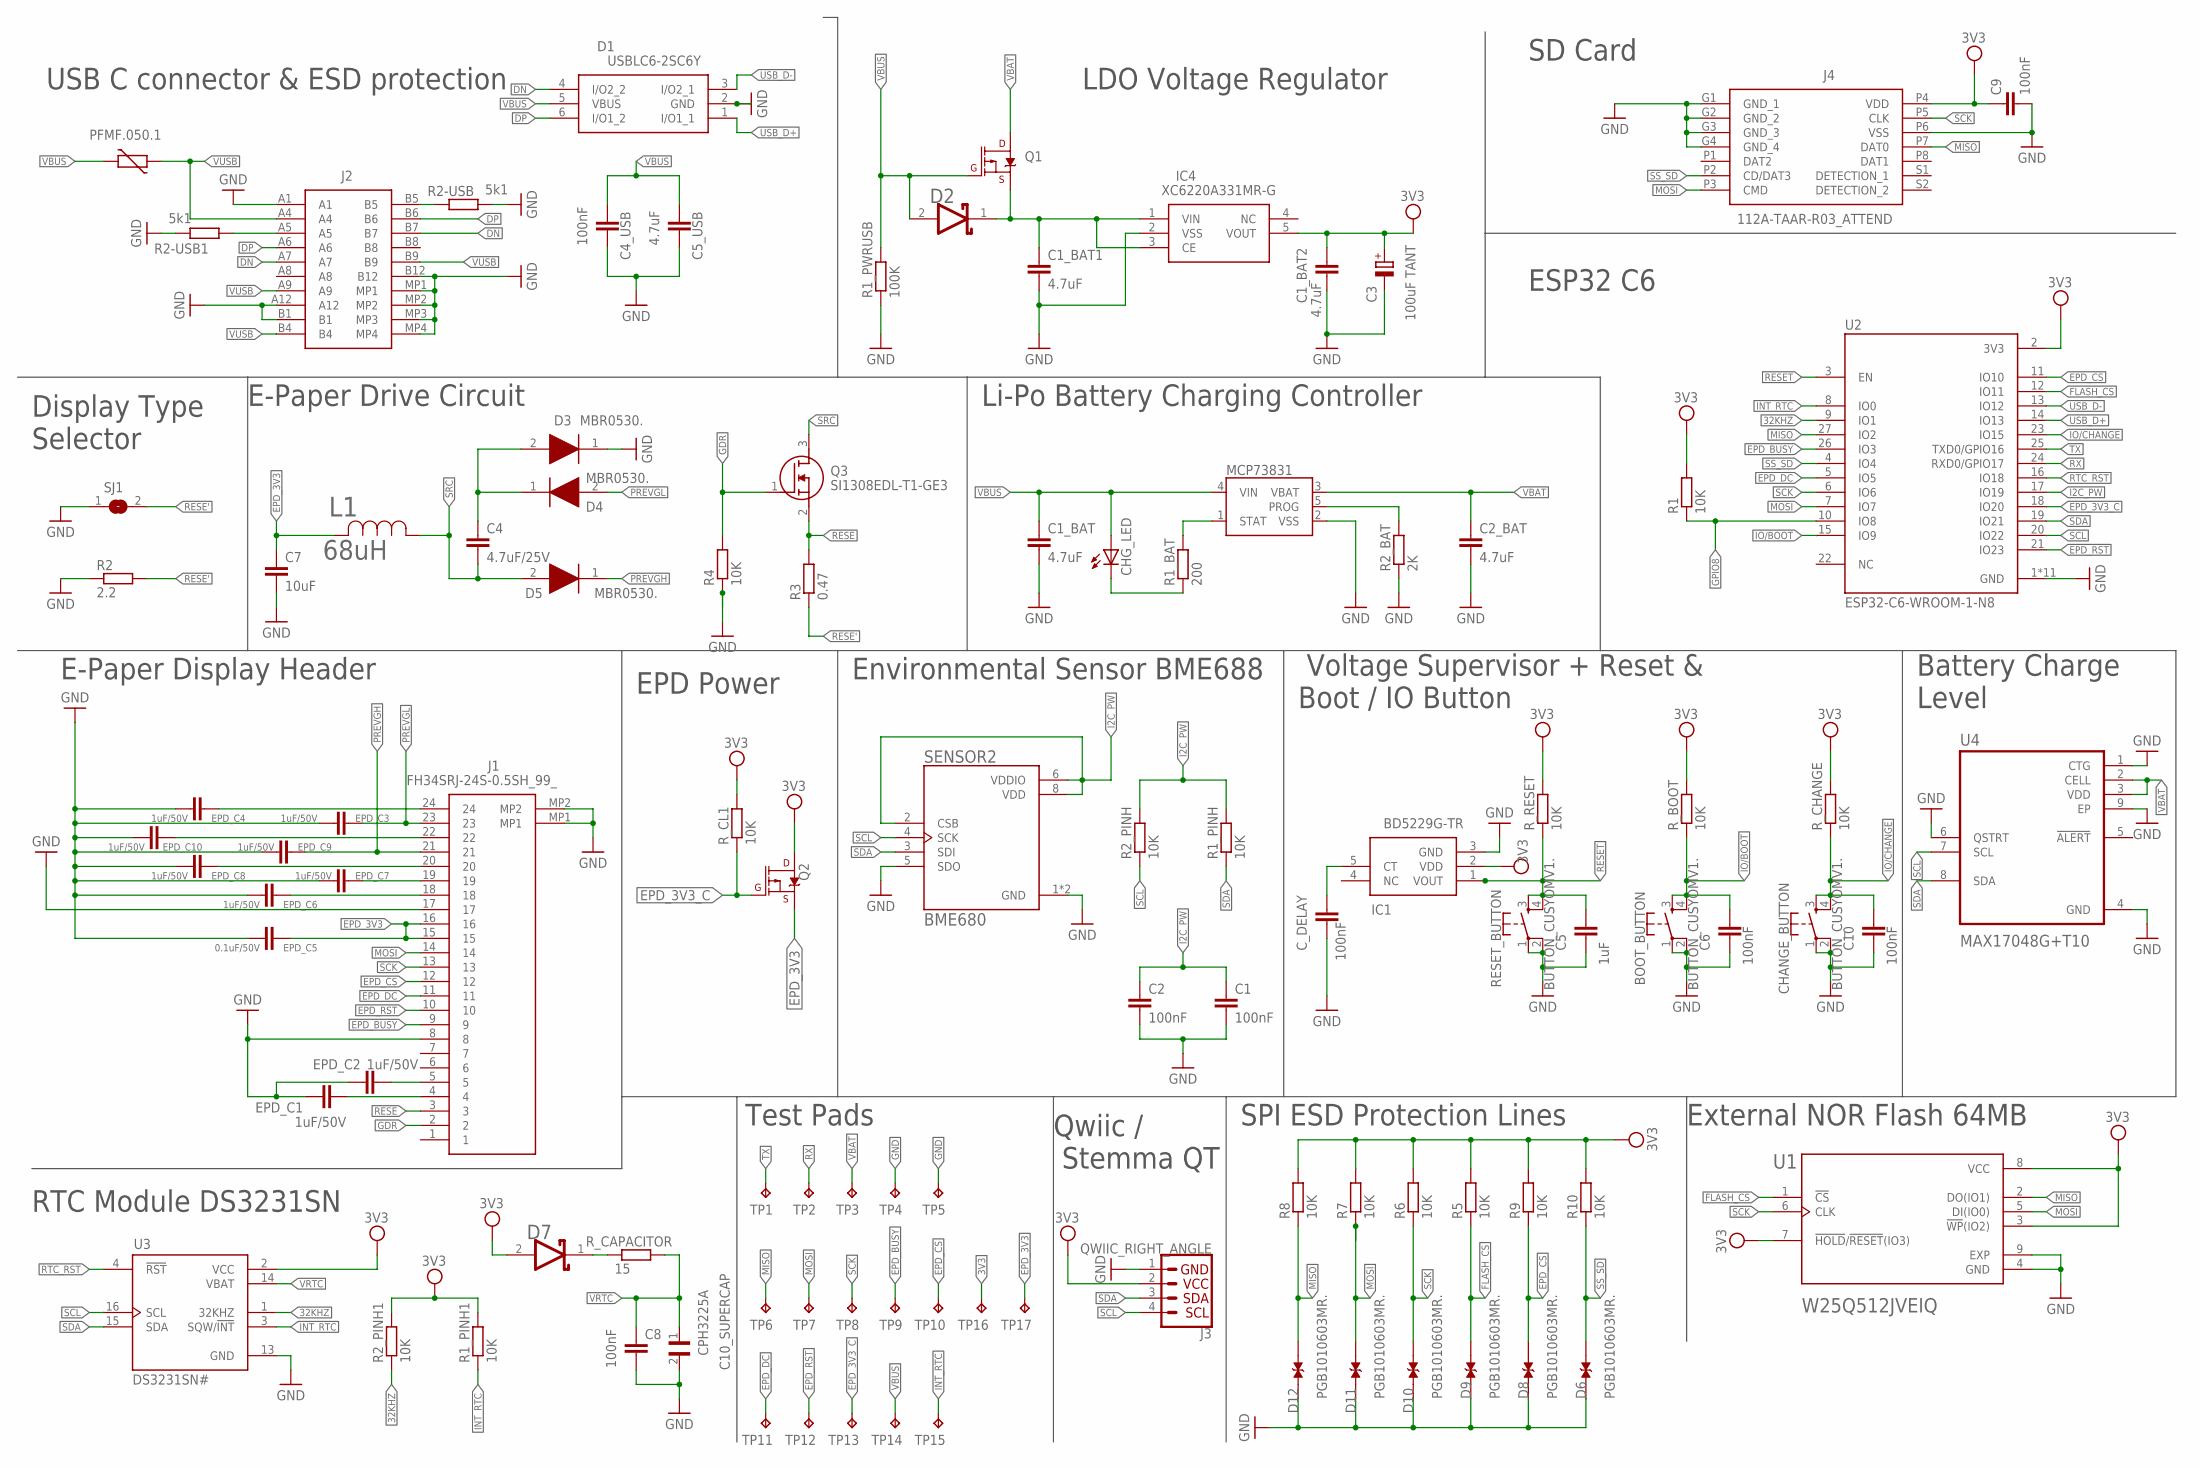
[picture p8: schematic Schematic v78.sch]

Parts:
BOOT_BUTTON: BUTTON_CUSYOMV1.; MYBUTTON
C1, C2, C4_USB, C6, C8, C9, C10: 100nF; EAGLE-LTSPICE_C0402
C1_BAT, C1_BAT1, C1_BAT2, C2_BAT, C5_USB: 4.7uF; EAGLE-LTSPICE_C0402
C3: 100uF TANT; RCL_CT3528
C4: 4.7uF/25V; EAGLE-LTSPICE_C0402
C5: 1uF; EAGLE-LTSPICE_C0402
C7: 10uF; EAGLE-LTSPICE_C0402
C10_SUPERCAP: CPH3225A; CAPCP3225X100N
CHANGE_BUTTON: BUTTON_CUSYOMV1.; MYBUTTON
CHG_LED: ADAFRUIT_LEDCHIP-LED0603; ADAFRUIT_CHIP-LED0603
C_DELAY: 100nF; EAGLE-LTSPICE_C0402
D1: USBLC6-2SC6Y; SOT95P280X145-6N
D2: ESP32_WROVER_AVX---SD0805S020S1R0_AVX_SD0805S020S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; ESP32_WROVER_AVX---SD0805S020S1R0_AVX_SD0805S020S1R0_0
D3, D4, D5: MBR0530.; SOD3716X135N
D6, D8, D9, D10, D11, D12: PGB1010603MR.; DIOC1608X36N
D7: SD0805S020S1R0; ESP32_WROVER_AVX---SD0805S020S1R0_AVX_SD0805S020S1R0_0
EPD_C1, EPD_C2, EPD_C3, EPD_C4, EPD_C6, EPD_C7, EPD_C8, EPD_C9, EPD_C10: 1uF/50V; EAGLE-LTSPICE_C0402
EPD_C5: 0.1uF/50V; EAGLE-LTSPICE_C0402
IC1: BD5229G-TR; SOT95P280X125-5N
IC4: XC6220A331MR-G; SOT95P280X120-5N
J1: FH34SRJ-24S-0.5SH_99_; FH34SRJ24S05SH99
J2: SAMACSYS_PARTS_USB4110-GF-A; SAMACSYS_PARTS_USB4110GFA
J3: QWIIC_RIGHT_ANGLE; JST04_1MM_RA
J4: 112A-TAAR-R03_ATTEND; 112ATAARR03ATTEND
L1: 68uH; IND_4828-WE-TPC_WRE
MCP73831: ESP32_WROVER_SPARKFUN-IC-POWER_MCP73831; ESP32_WROVER_SPARKFUN-IC-POWER_SOT23-5
PFMF.050.1: ESP32C6_VARISTORCN1812; ESP32C6_VARISTOR_CT/CN1812
Q1, Q2: 20V/4.2A/52mΩ/1.4W; ESP32_WROVER_SPARKFUN-DISCRETESEMI_SOT23-3
Q3: SI1308EDL-T1-GE3; SOT65P210X110-3N
R1, R1_PINH, R1_PINH1, R2_PINH, R2_PINH1, R4, R5, R6, R7, R8, R9, R10: 10K; ESP32_WROVER_EAGLE-LTSPICE_R0402
R1_BAT: 200; ESP32_WROVER_EAGLE-LTSPICE_R0402
R1_PWRUSB: 100K; ESP32_WROVER_EAGLE-LTSPICE_R0402
R2: 2.2; ESP32_WROVER_EAGLE-LTSPICE_R0402
R2-USB, R2-USB1: 5k1; ESP32_WROVER_EAGLE-LTSPICE_R0402
R2_BAT: 2K; ESP32_WROVER_EAGLE-LTSPICE_R0402
R3: 0.47; ESP32_WROVER_EAGLE-LTSPICE_R0402
RESET_BUTTON: BUTTON_CUSYOMV1.; MYBUTTON
R_BOOT: 10K; ESP32_WROVER_EAGLE-LTSPICE_R0402
R_CAPACITOR: 15; ESP32_WROVER_EAGLE-LTSPICE_R0402
R_CHANGE: 10K; ESP32_WROVER_EAGLE-LTSPICE_R0402
R_CL1: 10K; ESP32_WROVER_EAGLE-LTSPICE_R0402
R_RESET: 10K; ESP32_WROVER_EAGLE-LTSPICE_R0402
SENSOR2: BME680; ESP32_WROVER_BME680_PSON80P300X300X100-8N
SJ1: SJ
TP1: TX; TP20R
TP2: RX; TP20R
TP3: VBAT; TP20R
TP4, TP5: GND; TP20R
TP6: MISO; TP20R
TP7: MOSI; TP20R
TP8: SCK; TP20R
TP9: EPD_BUSY; TP20R
TP10: EPD_CS; TP20R
TP11: EPD_DC; TP20R
TP12: EPD_RST; TP20R
TP13: EPD_3V3_C; TP20R
TP14: VBUS; TP20R
TP15: INT_RTC; TP20R
TP16: 3V3; TP20R
TP17: EPD_3V3; TP20R
U1: W25Q512JVEIQ; SON127P600X800X80-9N
U2: ESP32-C6-WROOM-1-N8; XCVR_ESP32-C6-WROOM-1-N8
U3: DS3231SN#; SOIC127P1032X265-16N
U4: MAX17048G+T10; SON50P200X200X80-9N

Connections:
3V3: C1_BAT2.1, C3.+, C9.1, D7.2 (ANODE), IC1.2 (VDD), IC4.5 (VOUT), J3.2, J4.P4 (VDD), Q2.3 (D), R1.2, R1_PINH1.2, R2_PINH1.2, R5.2, R6.2, R7.2, R8.2, R9.2, R10.2, R_BOOT.2, R_CHANGE.2, R_CL1.2, R_RESET.2, TP16.TP, U1.3 (!WP!(IO2)), U1.7 (!HOLD!/!RESET!(IO3)), U1.8 (VCC), U2.2 (3V3), U3.2 (VCC)
32KHZ: R2_PINH1.1, U2.9 (IO1), U3.1 (32KHZ)
DN: D1.4 (I/O2_2), J2.A7, J2.B7
DP: D1.6 (I/O1_2), J2.A6, J2.B6
EPD_3V3: C7.1, EPD_C5.2, J1.15, J1.16, L1.2, Q2.2 (S), TP17.TP
EPD_3V3_C: Q2.1 (G), R_CL1.1, TP13.TP, U2.18 (IO20)
EPD_BUSY: J1.9, TP9.TP, U2.26 (IO3)
EPD_CS: D8.2, J1.12, R9.1, TP10.TP, U2.11 (IO10)
EPD_DC: J1.11, TP11.TP, U2.5 (IO5)
EPD_RST: J1.10, TP12.TP, U2.21 (IO23)
FLASH_CS: D9.2, R5.1, U1.1 (!CS), U2.12 (IO11)
GDR: J1.2, Q3.1 (G), R4.2
GND: BOOT_BUTTON.1, BOOT_BUTTON.2, C1.2, C1_BAT.2, C1_BAT1.2, C1_BAT2.2, C2.2, C2_BAT.2, C3.-, C4_USB.2, C5.2, C5_USB.2, C6.2, C7.2, C8.2, C9.2, C10.2, C10_SUPERCAP.2, CHANGE_BUTTON.1, CHANGE_BUTTON.2, C_DELAY.2, D1.2 (GND), D3.1 (K), D6.1, D8.1, D9.1, D10.1, D11.1, D12.1, EPD_C1.1, EPD_C2.1, EPD_C3.1, EPD_C4.1, EPD_C5.1, EPD_C6.1, EPD_C7.1, EPD_C8.1, EPD_C9.1, EPD_C10.1, IC1.3 (GND), IC4.2 (VSS), J1.8, J1.17, J1.MP1, J1.MP2, J2.A1, J2.A12, J2.B1, J2.B12, J2.MP1, J2.MP2, J2.MP3, J2.MP4, J3.1, J4.G1 (GND_1), J4.G2 (GND_2), J4.G3 (GND_3), J4.G4 (GND_4), J4.P6 (VSS), MCP73831.2 (VSS), R1_PWRUSB.1, R2.1, R2-USB.2, R2-USB1.1, R2_BAT.1, R4.1, RESET_BUTTON.1, RESET_BUTTON.2, SENSOR2.1 (GND), SENSOR2.5 (SDO), SENSOR2.7 (GND), SJ1.1, TP4.TP, TP5.TP, U1.4 (GND), U1.9 (EXP), U2.1 (GND), U2.28 (GND), U2.29_1 (GND), U2.29_2 (GND), U2.29_3 (GND), U2.29_4 (GND), U2.29_5 (GND), U2.29_6 (GND), U2.29_7 (GND), U2.29_8 (GND), U2.29_9 (GND), U3.13 (GND), U4.1 (CTG), U4.4 (GND), U4.6 (QSTRT), U4.9 (EP)
GPIO8: R1.1, U2.10 (IO8)
I2C_PW: C1.1, C2.1, R1_PINH.2, R2_PINH.2, SENSOR2.2 (CSB), SENSOR2.6 (VDDIO), SENSOR2.8 (VDD), U2.17 (IO19)
INT_RTC: R1_PINH1.1, TP15.TP, U2.8 (IO0), U3.3 (SQW/!INT)
IO/BOOT: BOOT_BUTTON.3, BOOT_BUTTON.4, C6.1, R_BOOT.1, U2.15 (IO9)
IO/CHANGE: C10.1, CHANGE_BUTTON.3, CHANGE_BUTTON.4, R_CHANGE.1, U2.23 (IO15)
MISO: D12.2, J4.P7 (DAT0), R8.1, TP6.TP, U1.2 (DO(IO1)), U2.27 (IO2)
MOSI: D11.2, J1.14, J4.P3 (CMD), R7.1, TP7.TP, U1.5 (DI(IO0)), U2.7 (IO7)
unnamed: J2.B5, R2-USB.1
unnamed: J2.A5, R2-USB1.2
unnamed: C1_BAT1.1, D2.1 (CATHODE), IC4.1 (VIN), IC4.3 (CE), Q1.2 (S)
unnamed: C4.1, D3.2 (A), D4.1 (K)
unnamed: MCP73831.1 (STAT), R1_BAT.2
unnamed: EPD_C1.2, J1.4
unnamed: MCP73831.5 (PROG), R2_BAT.2
unnamed: CHG_LED.C, R1_BAT.1
unnamed: EPD_C2.2, J1.5
unnamed: EPD_C8.2, J1.20
unnamed: EPD_C10.2, J1.22
unnamed: C_DELAY.1, IC1.5 (CT)
unnamed: EPD_C4.2, J1.24
unnamed: D7.1 (CATHODE), R_CAPACITOR.1
unnamed: EPD_C6.2, J1.18
unnamed: EPD_C7.2, J1.19
PREVGH: D5.1 (K), EPD_C9.2, J1.21
PREVGL: D4.2 (A), EPD_C3.2, J1.23
RESE: J1.3, Q3.2 (S), R3.2
RESE': R2.2, R3.1, SJ1.2
RESET: C5.1, IC1.1 (VOUT), RESET_BUTTON.3, RESET_BUTTON.4, R_RESET.1, U2.3 (EN)
RTC_RST: U2.16 (IO18), U3.4 (!RST)
RX: TP2.TP, U2.24 (RXD0/GPIO17)
SCK: D10.2, J1.13, J4.P5 (CLK), R6.1, TP8.TP, U1.6 (CLK), U2.6 (IO6)
SCL: J3.4, R2_PINH.1, SENSOR2.4 (SCK), U2.20 (IO22), U3.16 (SCL), U4.7 (SCL)
SDA: J3.3, R1_PINH.1, SENSOR2.3 (SDI), U2.19 (IO21), U3.15 (SDA), U4.8 (SDA)
SRC: C4.2, D5.2 (A), L1.1, Q3.3 (D)
SS_SD: D6.2, J4.P2 (CD/DAT3), R10.1, U2.4 (IO4)
TX: TP1.TP, U2.25 (TXD0/GPIO16)
USB_D+: D1.1 (I/O1_1), U2.14 (IO13)
USB_D-: D1.3 (I/O2_1), U2.13 (IO12)
VBAT: C2_BAT.1, MCP73831.3 (VBAT), Q1.3 (D), TP3.TP, U4.2 (CELL), U4.3 (VDD)
VBUS: C1_BAT.1, C4_USB.1, C5_USB.1, CHG_LED.A, D1.5 (VBUS), D2.2 (ANODE), MCP73831.4 (VIN), PFMF.050.1.2, Q1.1 (G), R1_PWRUSB.2, TP14.TP
VRTC: C8.1, C10_SUPERCAP.1, R_CAPACITOR.2, U3.14 (VBAT)
VUSB: J2.A4, J2.A9, J2.B4, J2.B9, PFMF.050.1.1

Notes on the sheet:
USB C connector & ESD protection
LDO Voltage Regulator
SD Card
Display Type Selector
E-Paper Drive Circuit
Li-Po Battery Charging Controller
ESP32 C6
E-Paper Display Header
EPD Power
Environmental Sensor BME688
Voltage Supervisor + Reset & Boot / IO Button
Battery Charge Level
RTC Module DS3231SN
Test Pads
Qwiic / Stemma QT
SPI ESD Protection Lines
External NOR Flash 64MB

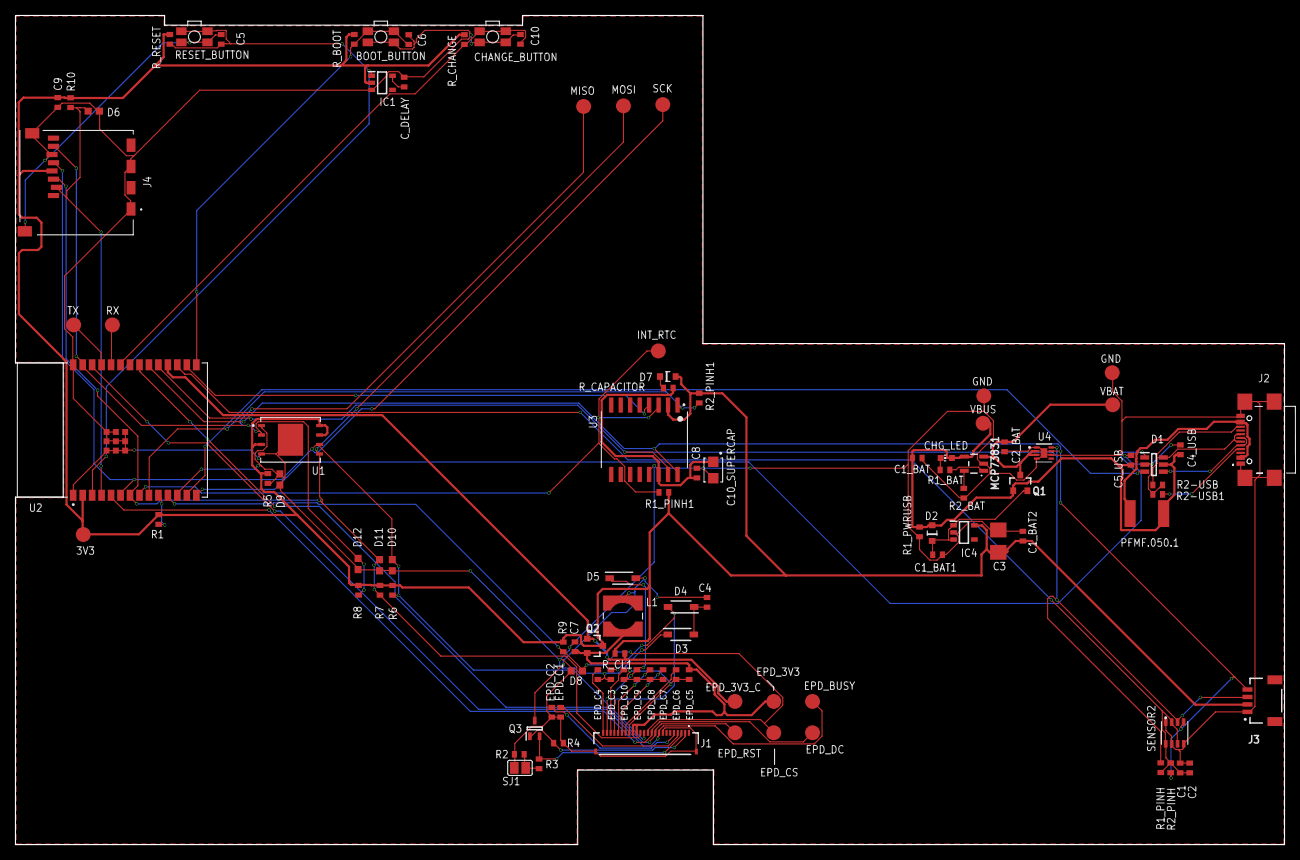
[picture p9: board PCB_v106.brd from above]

Board: 2 copper layers, 170.2 x 111.2 mm, 103 parts (0 on the bottom side), 55 nets.

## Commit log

2025-04-06 added hardware files
    [PCB v95.brd, Schematic_v72.sch]
2025-04-06 Added manufacturing
    [BOM.csv, PickAndPlace.csv]
2025-04-11 am rezolvat issue urile plus am eliminat vias urile pe power lines
    [PCB v95.brd, PCB_v106.brd, PickAndPlace.csv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]

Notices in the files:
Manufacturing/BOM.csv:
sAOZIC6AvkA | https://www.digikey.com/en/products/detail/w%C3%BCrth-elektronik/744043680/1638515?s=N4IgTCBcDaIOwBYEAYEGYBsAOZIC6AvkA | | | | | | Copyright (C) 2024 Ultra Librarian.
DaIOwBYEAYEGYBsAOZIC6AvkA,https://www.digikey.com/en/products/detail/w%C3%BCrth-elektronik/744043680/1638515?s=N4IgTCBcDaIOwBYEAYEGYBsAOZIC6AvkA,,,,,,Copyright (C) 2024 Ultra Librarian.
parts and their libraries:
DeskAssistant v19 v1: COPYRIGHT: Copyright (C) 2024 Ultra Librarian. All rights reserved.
